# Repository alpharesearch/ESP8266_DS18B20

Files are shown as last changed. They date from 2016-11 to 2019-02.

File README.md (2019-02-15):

# ESP8266_DS18B20

Most parts are optional, this is just a little breakout board for the esp8266. I just used parts that I had already at home. With the little prototyping area it allows to add different little projects. For example I have a some boards connected to Smartthings hub. Right now I'm using 3 versions: log 5 temperatures, red and green status LED, press two buttons on bed remote control.

https://htmlpreview.github.io/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

Here is the string for "Formatted row" at the IFTTT recipe I use:

=TIMEVALUE(SUBSTITUTE("{{OccurredAt}}"," at ", " ")) + DATEVALUE(SUBSTITUTE("{{OccurredAt}}"," at ", " "))||| {{EventName}} ||| {{Value1}} |||{{Value2}} ||| {{Value3}}|||={{Value3}}*9/5+32|||=IF("{{Value1}}"="40:255:148:214:68:22:3", "clean to inside", "")& IF("{{Value1}}"="40:255:252:69:80:22:4", "water heater room", "")& IF("{{Value1}}"="40:255:229:240:68:22:3", "dirty inside", "")&IF("{{Value1}}"="40:255:111:38:80:22:4", "clean from outside", "")&IF("{{Value1}}"="40:255:95:255:68:22:3", "dirty to outside", "")

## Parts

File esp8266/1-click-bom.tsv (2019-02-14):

References | Qty | Description
C1 | 1 | CP 10uf C Radial D5 L6 P2.5
C2 | 1 | CP 100uf C Radial D8 L11.5 P3.5
C3 | 1 | C Small Disc D3 P2.5
D1 | 1 | D-RESCUE-esp8266 D Diode DO-41 SOD81 Horizontal RM10
J1 | 1 | Screw Terminal 1x02-RESCUE-esp8266 1x02 bornier2
J2 | 1 | Screw Terminal 1x03 bornier3
JP1 | 1 | JUMPER NO Small TEST POINT 2PADS
P1 | 1 | CONN 02X04 Socket Strip Straight 2x04
P2 | 1 | CONN 01X03 Pin Header Straight 1x03
P3, P4, P5, P6 | 4 | CONN 01X03 Socket Strip Straight 1x03
PROG1, RESET1 | 2 | SW PUSH 6mm
R2, R1 | 2 | R 2.2k Resistor Horizontal RM10mm
R3 | 1 | R 4.7k Resistor Horizontal RM10mm
U1 | 1 | LD1117S33TR TO-220 Neutral123 Vertical

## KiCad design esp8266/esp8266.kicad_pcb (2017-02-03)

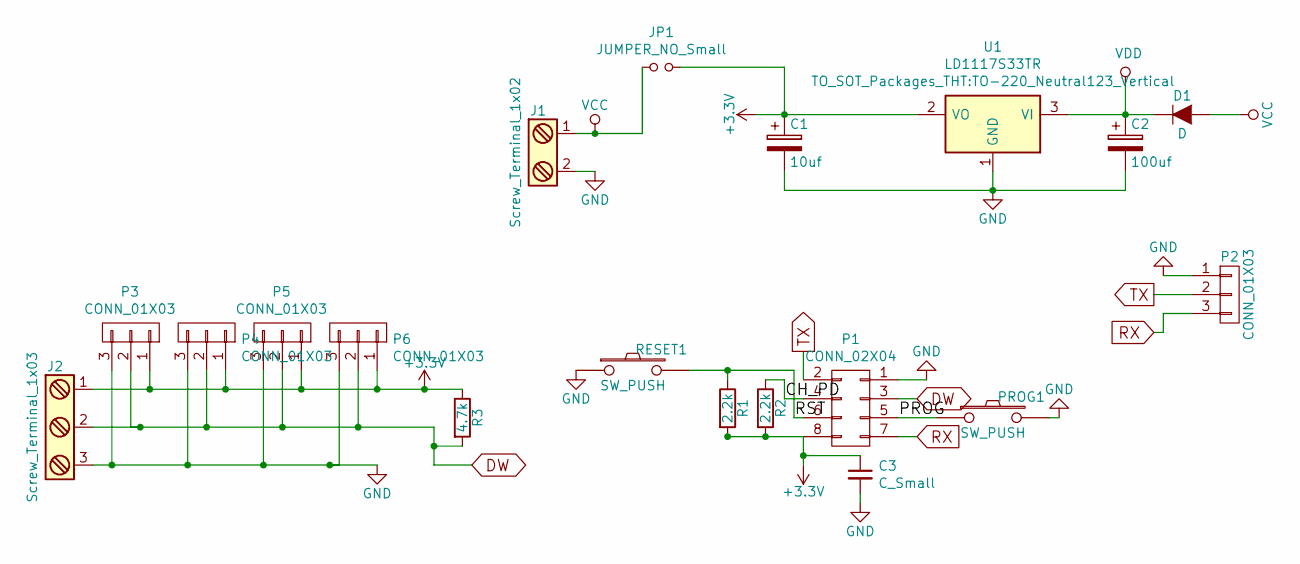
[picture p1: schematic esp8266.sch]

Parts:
C1: 10uf; C_Radial_D5_L6_P2.5
C2: 100uf; C_Radial_D8_L11.5_P3.5
C3: C_Small; C_Disc_D3_P2.5
D1: D; Diode_DO-41_SOD81_Horizontal_RM10
J1: Screw_Terminal_1x02; bornier2
J2: Screw_Terminal_1x03; bornier3
JP1: JUMPER_NO_Small; TEST_POINT_2PADS
P1: CONN_02X04; Socket_Strip_Straight_2x04
P2: CONN_01X03; Pin_Header_Straight_1x03
P3, P4, P5, P6: CONN_01X03; Socket_Strip_Straight_1x03
PROG1: SW_PUSH; SW_PUSH_6mm
R1, R2: 2.2k; Resistor_Horizontal_RM10mm
R3: 4.7k; Resistor_Horizontal_RM10mm
RESET1: SW_PUSH; SW_PUSH_6mm
U1: LD1117S33TR; TO-220_Neutral123_Vertical

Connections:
+3V3: C1.1, C3.1, J2.1, JP1.2, P1.8, P3.1, P4.1, P5.1, P6.1, R1.2, R2.2, R3.1, U1.2 (VO)
/CH_PD: P1.4, R2.1
/PROG: P1.5, PROG1.1
/RST: P1.6, R1.1, RESET1.2
DW: J2.2, P1.3, P3.2, P4.2, P5.2, P6.2, R3.2
GND: C1.2, C2.2, C3.2, J1.2, J2.3, P1.1, P2.1, P3.3, P4.3, P5.3, P6.3, PROG1.2, RESET1.1, U1.1 (GND)
RX: P1.7, P2.3
TX: P1.2, P2.2
VCC: D1.2 (A), J1.1, JP1.1
VDD: C2.1, D1.1 (K), U1.3 (VI)

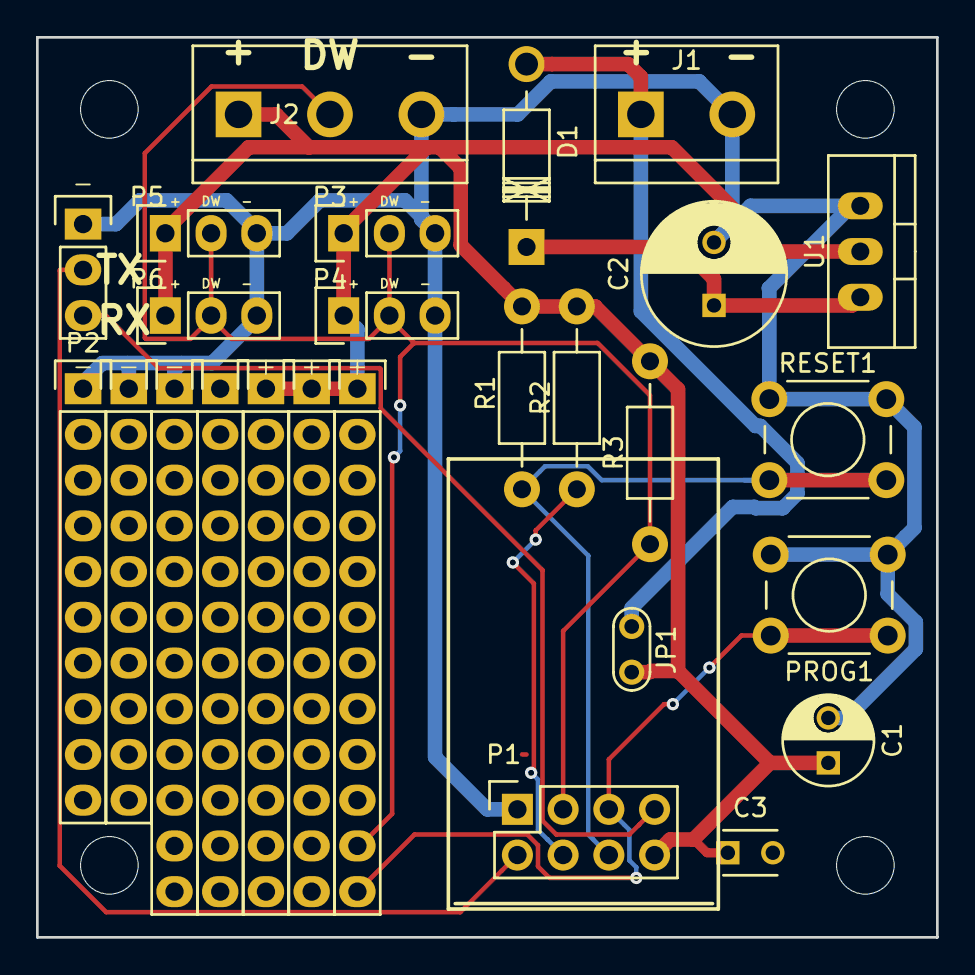
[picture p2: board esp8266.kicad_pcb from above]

Board: 2 copper layers, 50.0 x 50.0 mm, 19 parts (0 on the bottom side), 10 nets.

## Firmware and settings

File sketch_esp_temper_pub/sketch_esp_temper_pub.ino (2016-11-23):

/*
  Created by Igor Jarc
  Greatly modified by Markus Schulz
 
 Code based on https://github.com/DennisSc/easyIoT-ESPduino/blob/master/sketches/ds18b20.ino
 
 External libraries:
 - https://github.com/adamvr/arduino-base64
 - https://github.com/milesburton/Arduino-Temperature-Control-Library
 
 This program is free software; you can redistribute it and/or
 modify it under the terms of the GNU General Public License
 version 2 as published by the Free Software Foundation.
 */

#include <ESP8266WiFi.h>
#include <OneWire.h>
#include <DallasTemperature.h>

//AP definitions
#define AP_SSID "your SSID"
#define AP_PASSWORD "rour AP password"

// IFTTT server definitions
#define IFTTT_IP_ADDRESS  "maker.ifttt.com"
#define IFTTT_PORT        80
#define IFTTT_KEY "your_key from the IFTTT web page"

#define REPORT_INTERVAL1 180 // forced update after how many little cycles (180s * 5s / 60s = 15 min).
#define REPORT_INTERVAL2 5 // in sec for litte cycle


#define ONE_WIRE_BUS 2  // DS18B20 pin
OneWire oneWire(ONE_WIRE_BUS);
DallasTemperature DS18B20(&oneWire);


#define USER_PWD_LEN 40
char unameenc[USER_PWD_LEN];
float oldTemp[16];
int dcount, cnt1;


void setup() {
  Serial.begin(115200);
  
  wifiConnect();

  cnt1 = REPORT_INTERVAL1;  
  DS18B20.begin();
  dcount =  DS18B20.getDeviceCount();
  DS18B20.setResolution(12);
  for(int i = 0; i != dcount; i++) {
        oldTemp[i]=-1;
  } 
}

void loop() {
  float temp[16];
  
  do {
    //dcount =  DS18B20.getDeviceCount();
    Serial.print("DS18B20 found: ");
    Serial.println(dcount);
    DS18B20.requestTemperatures();
    for(int i = 0; i != dcount; i++) {
        temp[i] = DS18B20.getTempCByIndex(i);
        Serial.print("Temperature"+String(i)+": "+String(temp[i])+" ");
        Serial.println(oldTemp[i]);
    } 
  } while (temp[0] == 85.0 || temp[0] == (-127.0));
  
  for(int i = 0; i != dcount; i++) {
    if (comp_diff(temp[i],oldTemp[i],0.5))
    {
      sendTeperature(i,temp[i]);
      oldTemp[i] = temp[i];
    }
  } 
  
  int cnt2 = REPORT_INTERVAL2;
  
  Serial.print("Foreced update in "+String(cnt1*cnt2)+"s; Sleeping for "+String(cnt2)+"s ");
  while(cnt2--) {
    delay(1000);
    Serial.print(".");
  }
  
  cnt1--;
  if(cnt1==0){
    cnt1 = REPORT_INTERVAL1;
    for(int i = 0; i != dcount; i++) {
      oldTemp[i]=-1;
    } 
  } 
  
  Serial.println("Done");
}

void wifiConnect()
{
    Serial.print("Connecting to AP");
    WiFi.softAPdisconnect(true);
    WiFi.begin(AP_SSID, AP_PASSWORD);
    while (WiFi.status() != WL_CONNECTED) {
    delay(1000);
    Serial.print(".");
  }
  
  Serial.println("");
  Serial.println("WiFi connected");  
}

void sendTeperature(int num, float temp)
{  
   WiFiClient client;
   
   while(!client.connect(IFTTT_IP_ADDRESS, IFTTT_PORT)) {
    Serial.println("connection failed");
    wifiConnect(); 
  }
  DeviceAddress  ds_addr;
  DS18B20.getAddress(ds_addr, num);
  String url = "";
  String event = "air";
  url += "/trigger/"+event+"/with/key/"+String(IFTTT_KEY)+"?value1="+addr_to_str(ds_addr)+"&value2="+String(num)+"&value3="+String(temp); // generate EasIoT server node URL

  Serial.print("POST data to URL: ");
  Serial.println(url);
  
  client.print(String("GET ") + url + " HTTP/1.1\r\n" +
               "Host: " + String(IFTTT_IP_ADDRESS) + "\r\n" + 
               "Connection: close\r\n" + 
               "Content-Length: 0\r\n" + 
               "\r\n");

  delay(100);
    while(client.available()){
    String line = client.readStringUntil('\r');
    Serial.print(line);
  }
  
  Serial.println();
  Serial.println("Connection closed");
}

String addr_to_str(DeviceAddress addr)
{
  String ret = String(addr[0]);
  for(int i = 1; i != 7; i++) {
  ret = ret + ":" + String(addr[i]); 
  }
  
  return ret; 
}

bool comp_diff(float comp1, float comp2, float diff)
{
  float temp = comp1 - comp2;
  temp = abs(temp);
  Serial.print("Temperature: "+String(comp1)+", "+String(comp2)+", Delta temp: ");
  Serial.println(temp);
  return temp > diff; 
}

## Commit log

2016-11-12 changed to LD1117
    [esp8266.kicad_pcb, esp8266.sch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]
2016-11-12 get some errors DRC corrected
    [esp8266.kicad_pcb, esp8266.sch]
2016-11-12 arduino IDE needs this folder
2016-11-13 add component description to back silk
    [esp8266.kicad_pcb, esp8266.sch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]
2016-11-14 try to add switch to 3d view
    [esp8266.kicad_pcb]
2017-02-03 add C3
    [esp8266.kicad_pcb, esp8266.sch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]
2018-11-18 interactive html bom
2019-02-14 kicad 5
    [esp8266.sch]
